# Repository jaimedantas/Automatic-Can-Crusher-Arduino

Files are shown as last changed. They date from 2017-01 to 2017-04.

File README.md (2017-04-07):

# Automatic Can Crusher
This project is a fully automatic can crusher based on the microcontroller ATmega328p Arduino Uno. The machine is made of two hydraulic rams and an Arduino which has a LDR and a LED as a can sensor.
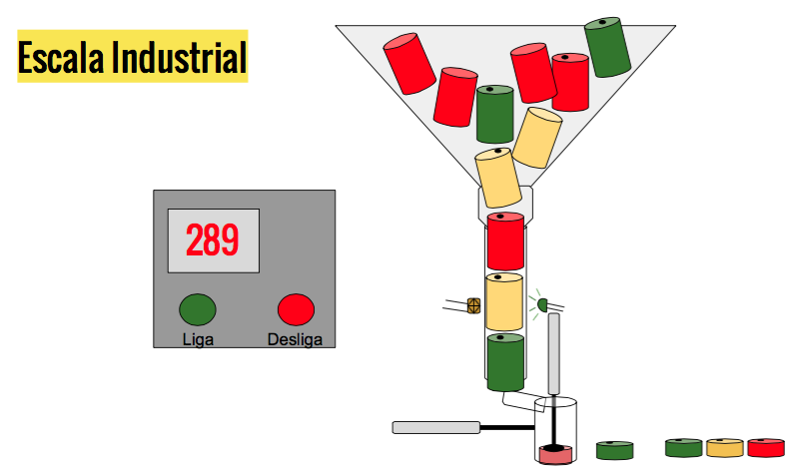
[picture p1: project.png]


There are two relays for switching the hydraulic cylinders. 
### The figure below shows the Arduino and the circuit used

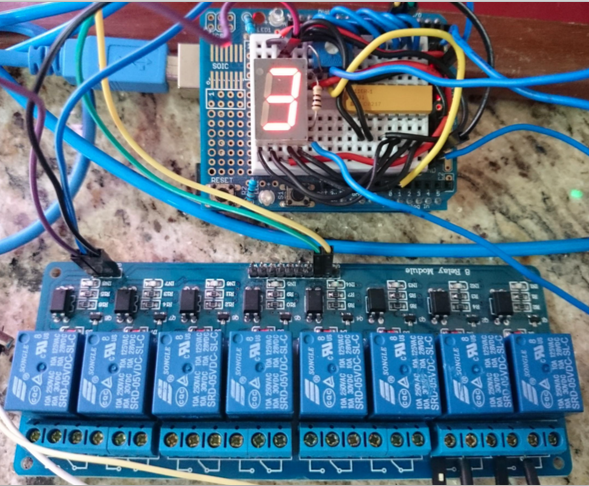
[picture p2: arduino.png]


If you wish to know more about this project, you can read the [report](https://github.com/jaimedantas/Automatic-Can-Crusher-Arduino/blob/master/full_report.pdf) written in Portuguese. You can also watch the video of this project on [YouTube](https://www.youtube.com/watch?v=sCqibvRW4SI)

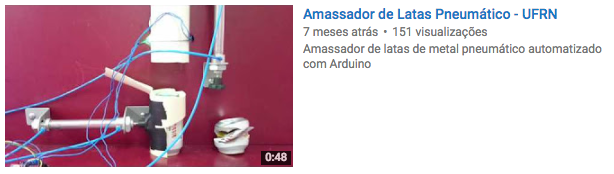
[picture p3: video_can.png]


https://www.youtube.com/watch?v=sCqibvRW4SI

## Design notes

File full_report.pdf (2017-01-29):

# Controle de Sistema Eletropneumático com µC ATmega328P

Alexandre Luz
Ana Jamile
Jaime Dantas
Ramon Fava

# Objetivo

- Desenvolver um amassador de latas utilizando um microcontrolador ATmega 328p e fazendo uso dos conceitos abordados na disciplina de Sistemas Digitais, tais como: interfaces de entrada e saída de dados digitais e analógicos, operações com registradores, conversor analógico e temporizadores.

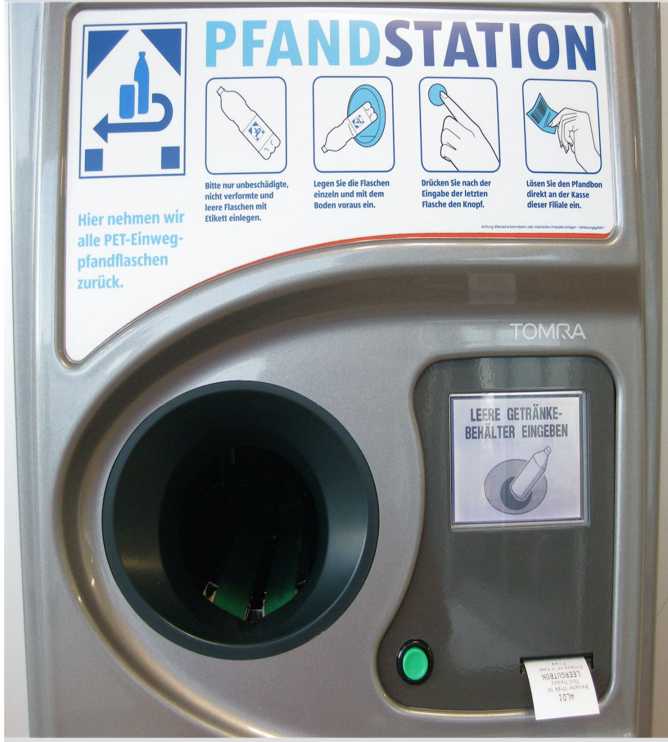
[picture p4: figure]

# Aplicabilidade

- Postos de coleta e compressão de latas em locais de fácil acesso como supermercados.
- Latas por dinheiro.
- Campanhas de incentivo à reciclagem.

# Materiais utilizados

- Cano PVC 75 mm
- Placa de MDF
- Fita isolante
- Arame
- 10 parafusos
- Latas
- 2 atuadores pneumáticos Festo
- Compressor
- Arduino Uno
- 1 LED
- Sensor LDR
- 2 Relés
- 1 Display de 7 segmentos
- Resistências
- Potenciômetro

# Atuadores Pneumáticos - Características

As principais características dos atuadores pneumáticos são:

- Apresentam baixa rigidez devido à compressibilidade do ar
- Não há precisão na parada em posições intermediárias
- Apresentam uma favorável relação peso/potência
- Dimensões reduzidas
- Segurança à sobrecarga
- Facilidade de inversão
- Proteção à explosão

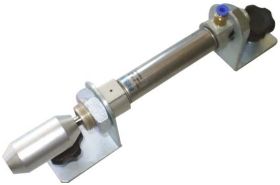
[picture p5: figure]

# Atuadores Pneumáticos - Aplicações

- Prensas pneumáticas
- Dispositivos de fixação de peças em máquinas ferramenta e esteiras
- Acionamento de portas de um ônibus urbano ou dos trens do metrô
- Sistemas automatizados para alimentação de peças
- Robôs industriais para aplicações que não exijam posicionamento preciso

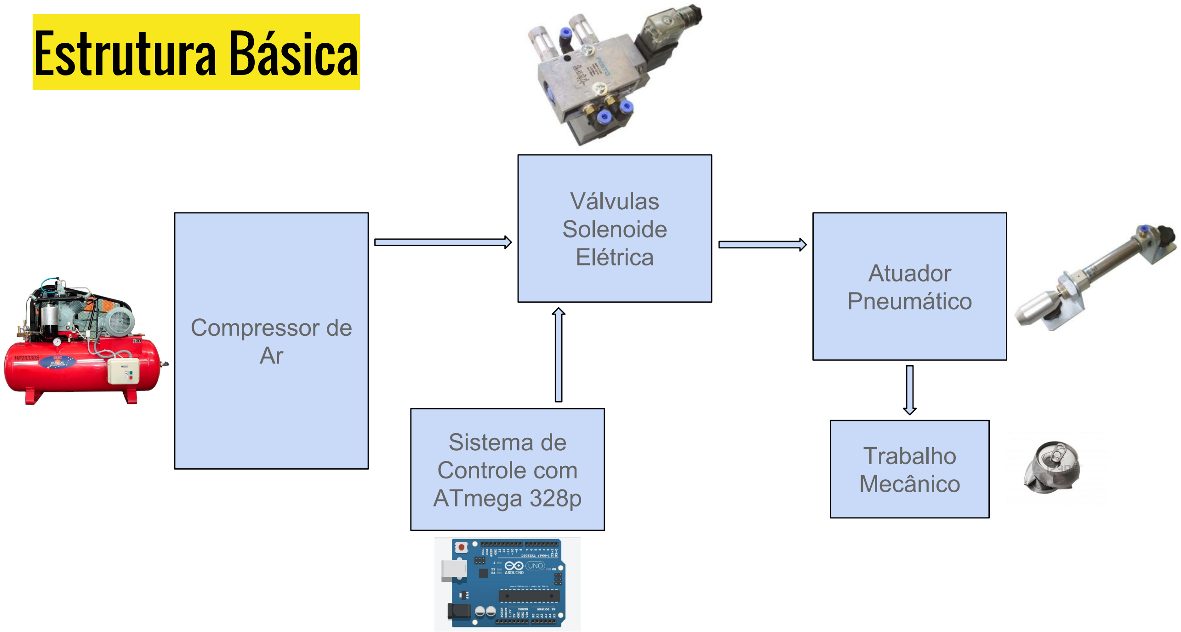
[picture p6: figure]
Estrutura Básica; Sistema de Controle com ATmega 328p; Compressor de Ar; Válvulas Solenoide; Elétrica; Atuador; Pneumático; Trabalho Mecânico

# Válvula Pneumática

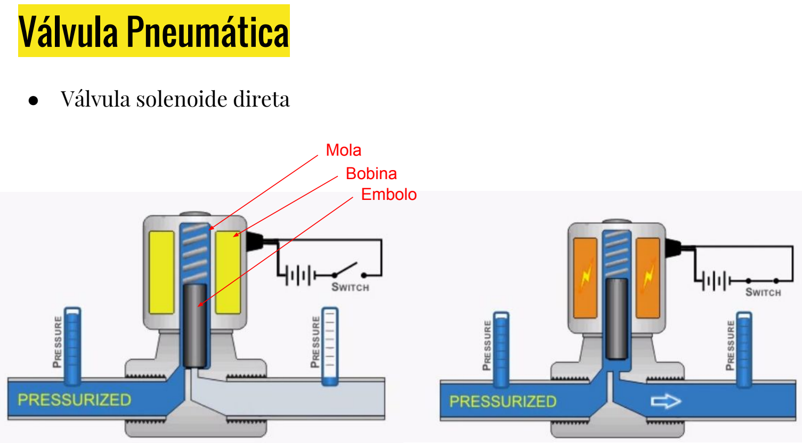
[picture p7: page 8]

- Válvula solenoide direta

Mola
Bobina
| Embolo

# Válvula Pneumática

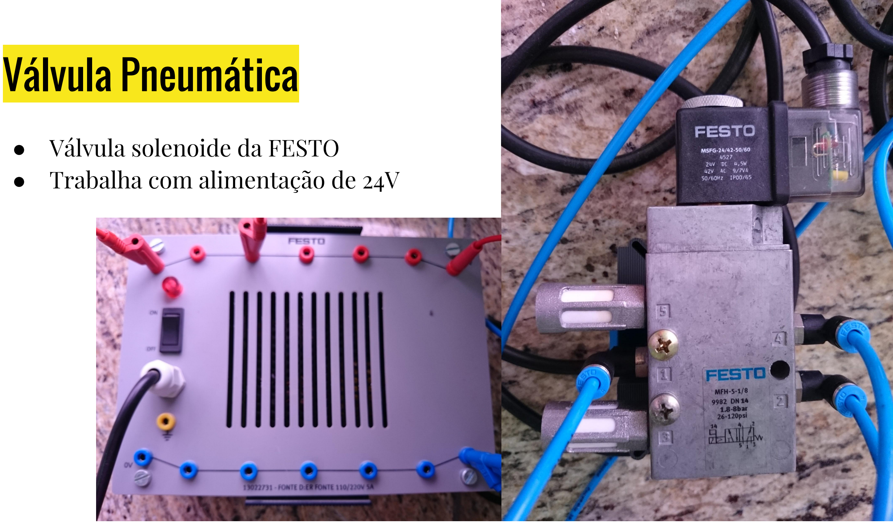
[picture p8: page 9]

- Válvula solenoide da FESTO
- Trabalha com alimentação de 24V

Incidência de Luz | LDR

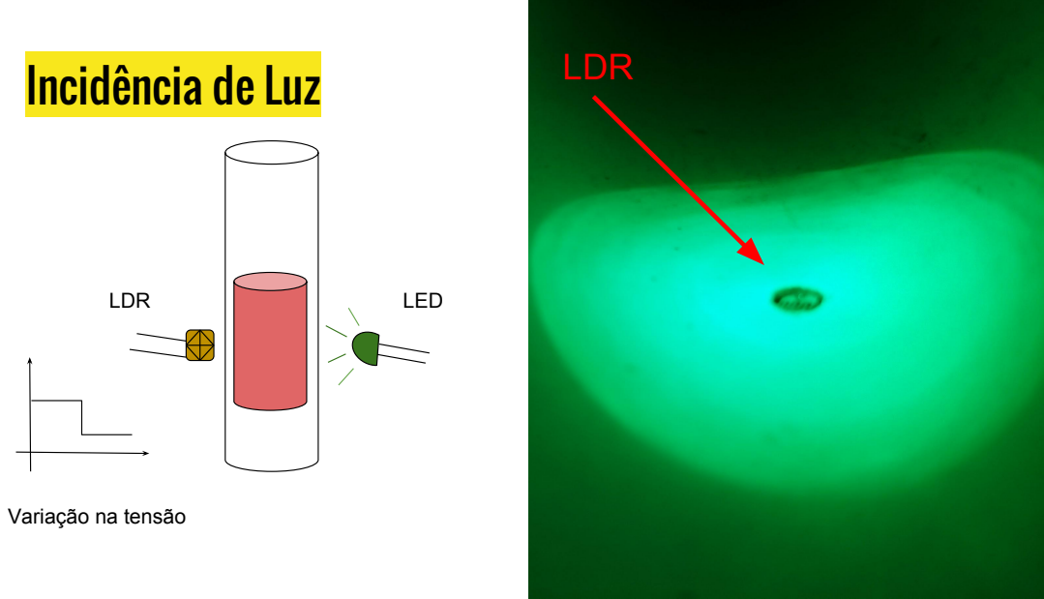
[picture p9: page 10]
LDR; LED

Variação na tensão

# Circuito

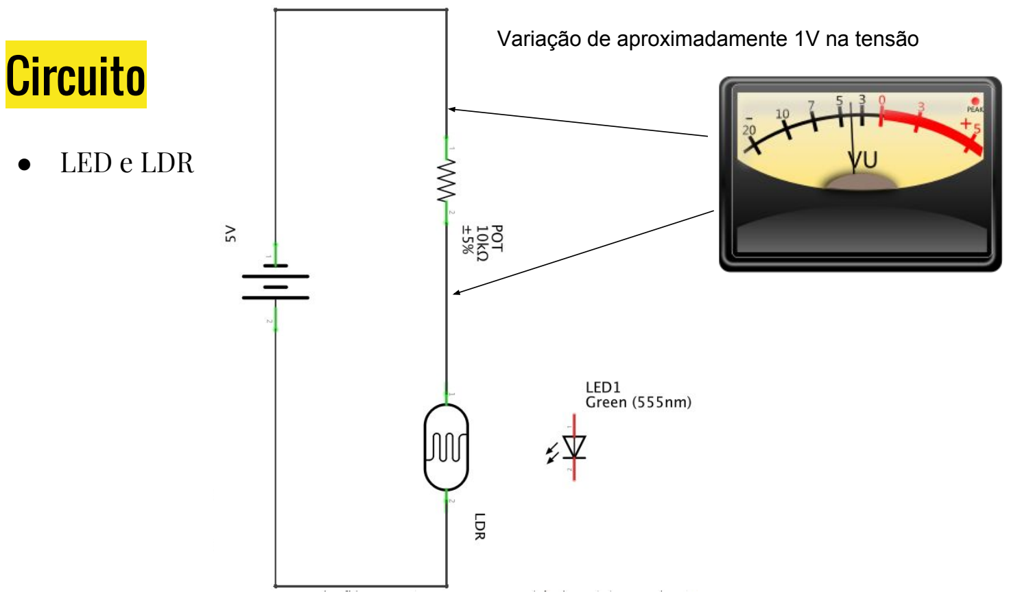
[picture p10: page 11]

- LED e LDR

Variação de aproximadamente 1V na tensão

# Funcionamento

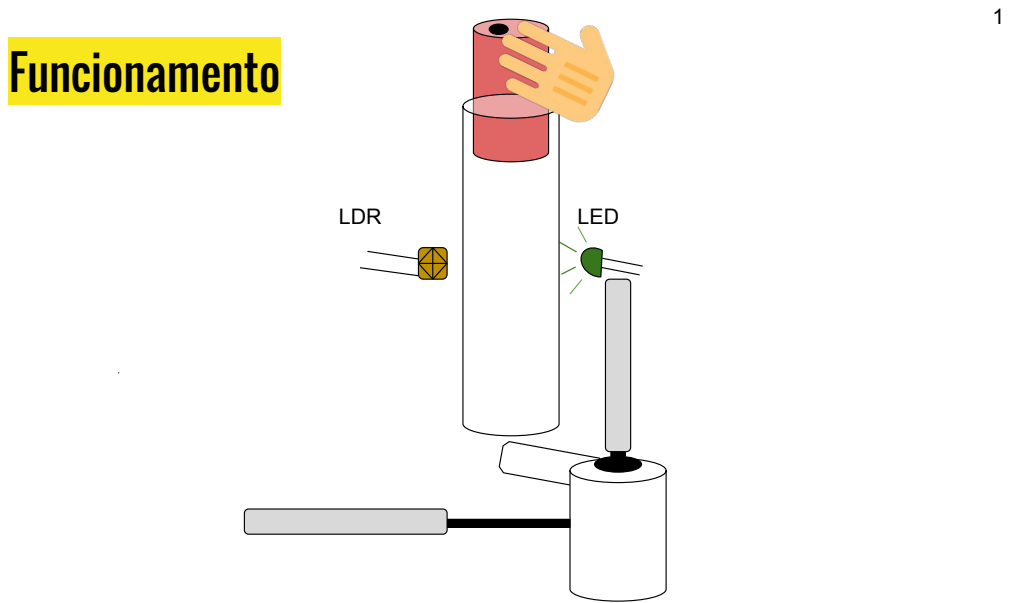
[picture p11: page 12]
LDR; LED

# Funcionamento

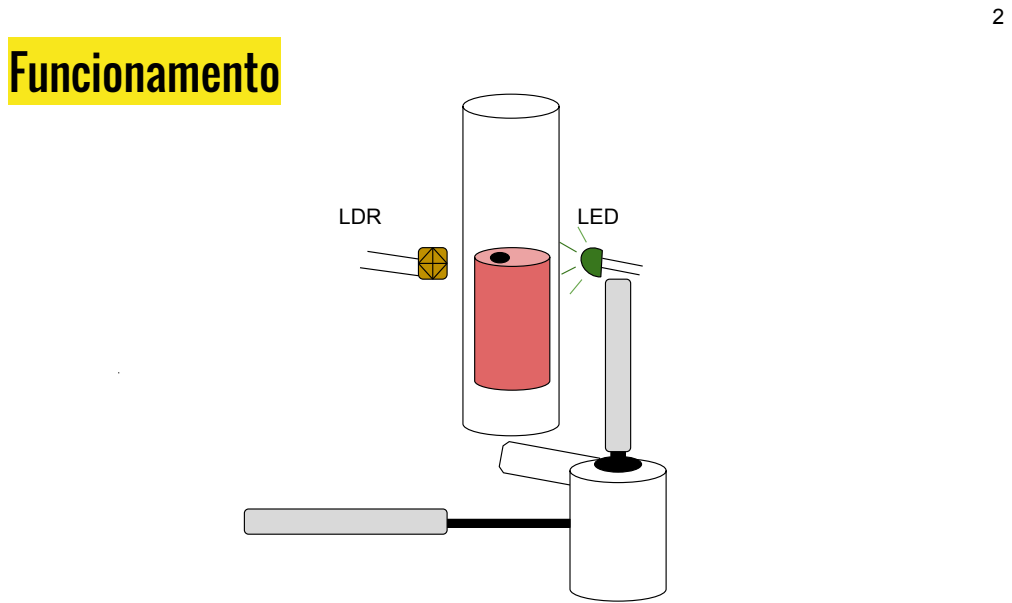
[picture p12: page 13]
LDR; LED

# Funcionamento

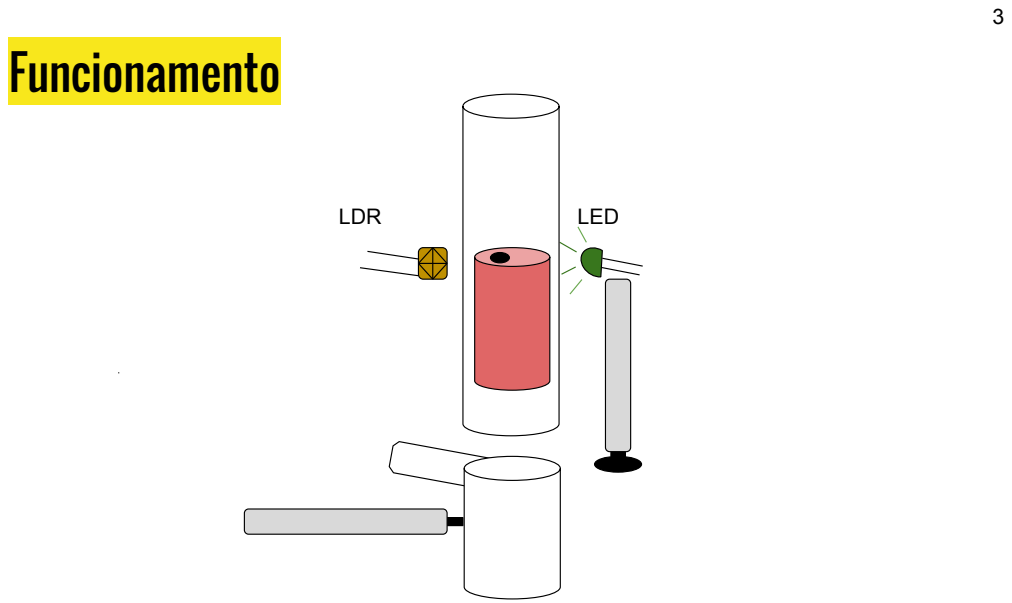
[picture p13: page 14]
LDR; LED

# Funcionamento

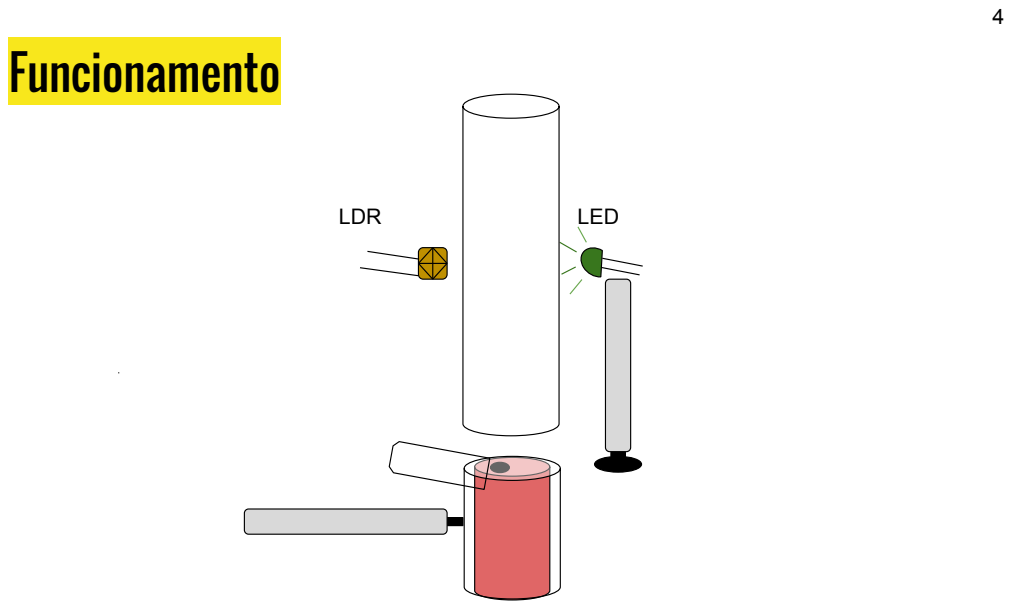
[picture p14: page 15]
LDR; LED

# Funcionamento

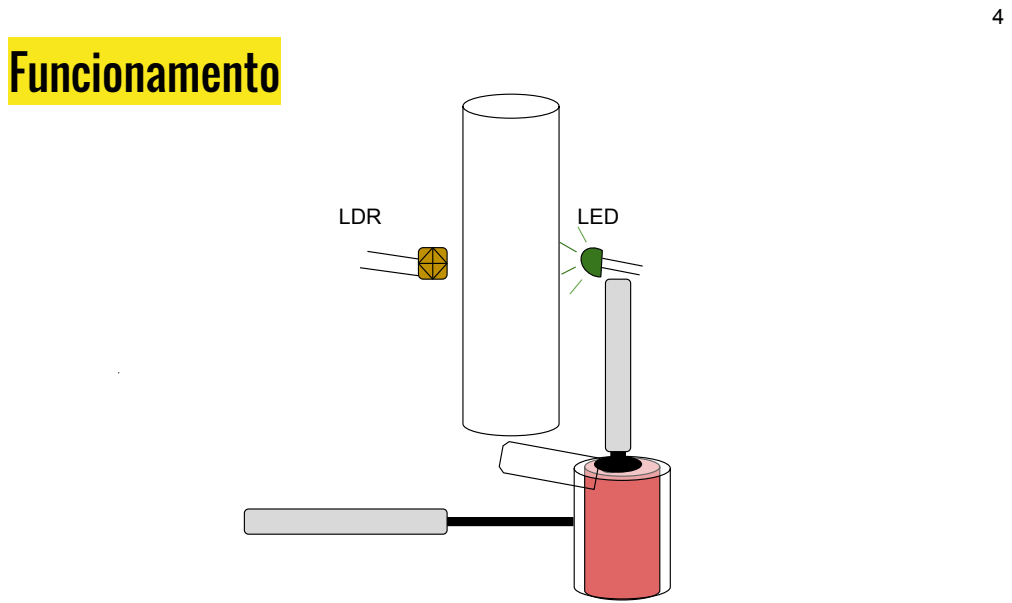
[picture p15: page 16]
LDR; LED

# Funcionamento

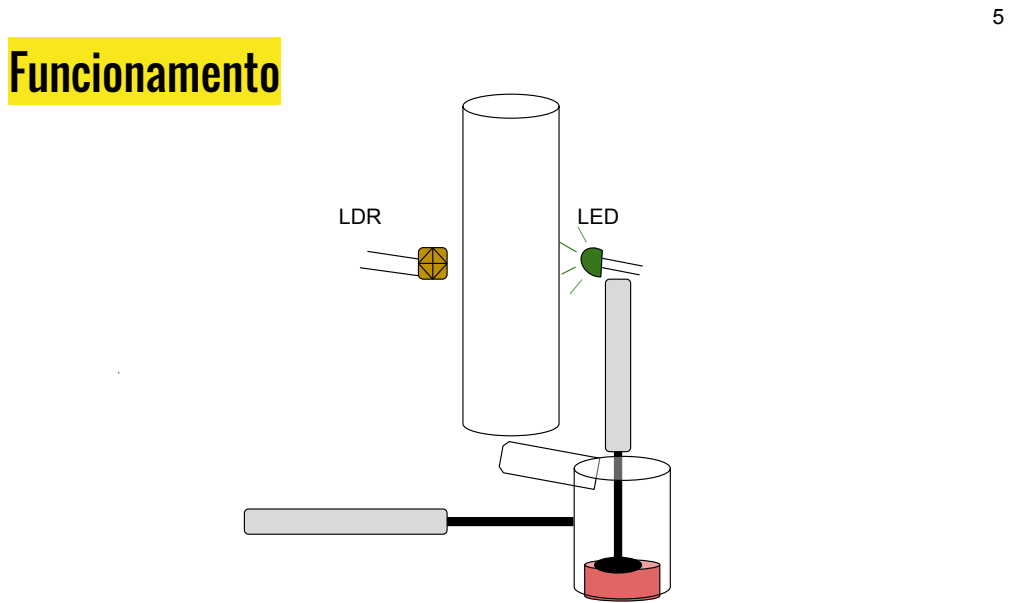
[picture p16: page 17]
LDR; LED

# Escala Industrial

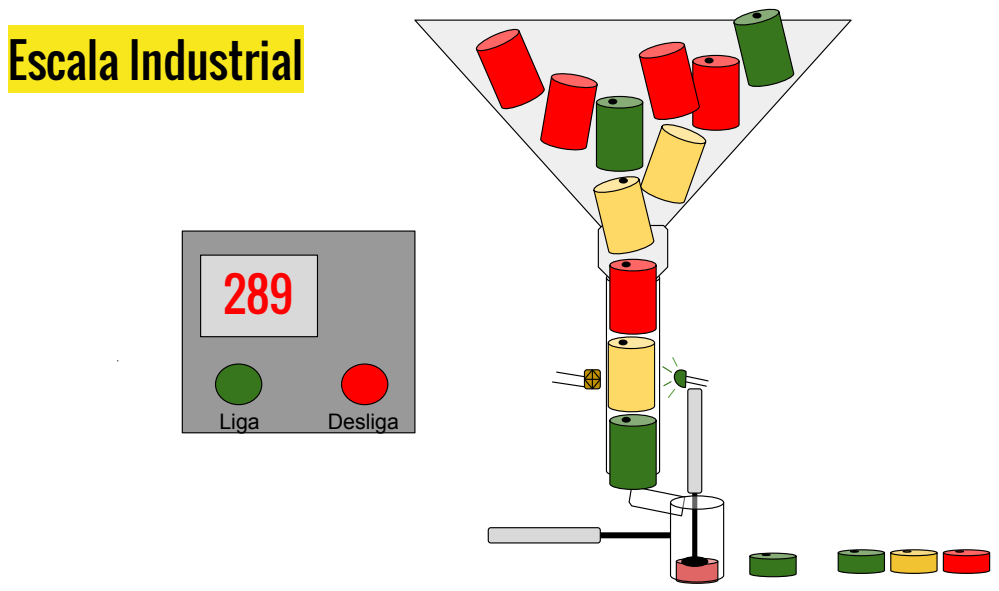
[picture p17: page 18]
Liga; Desliga

# Circuito

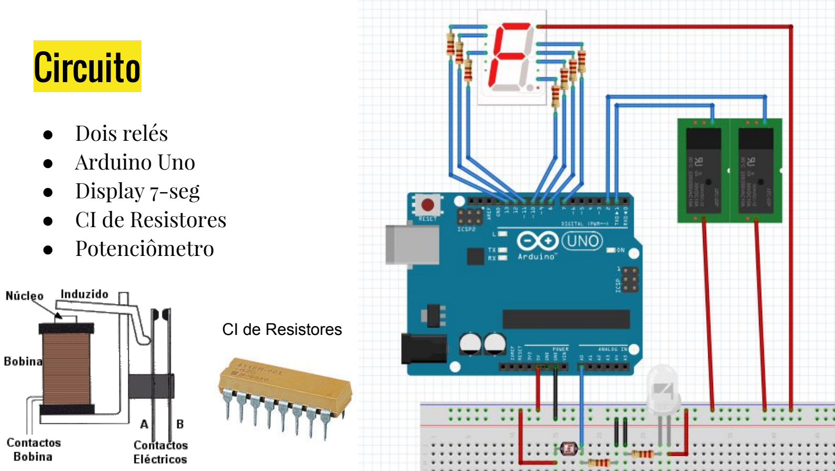
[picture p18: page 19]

CI de Resistores

- Dois relés
- Arduino Uno
- Display 7-seg
- CI de Resistores
- Potenciômetro

# Circuito

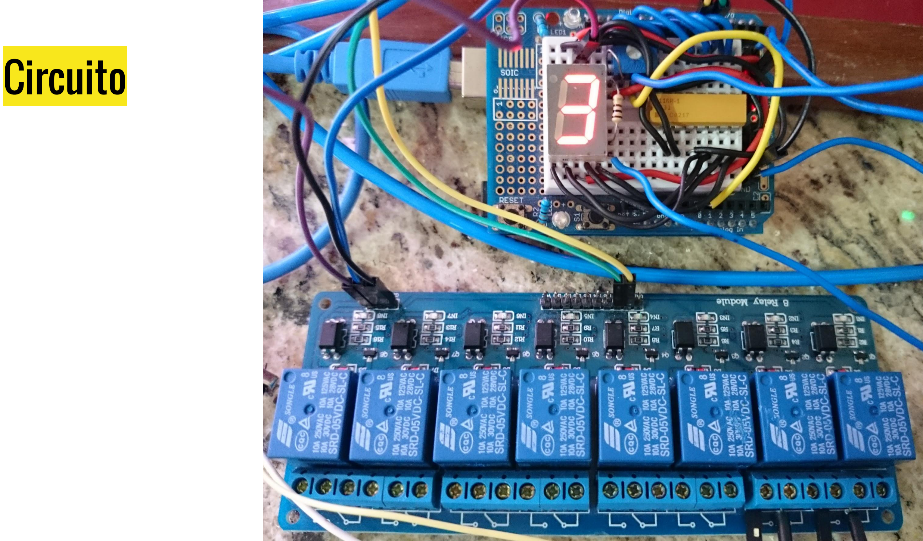
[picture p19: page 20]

# Máquina montada

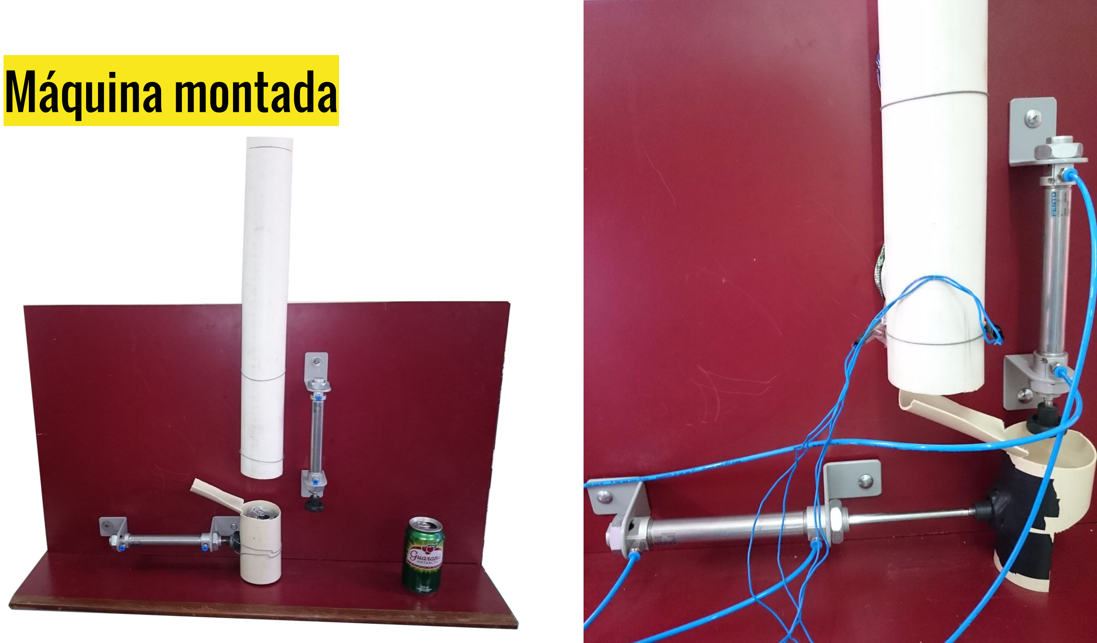
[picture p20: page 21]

# Programação

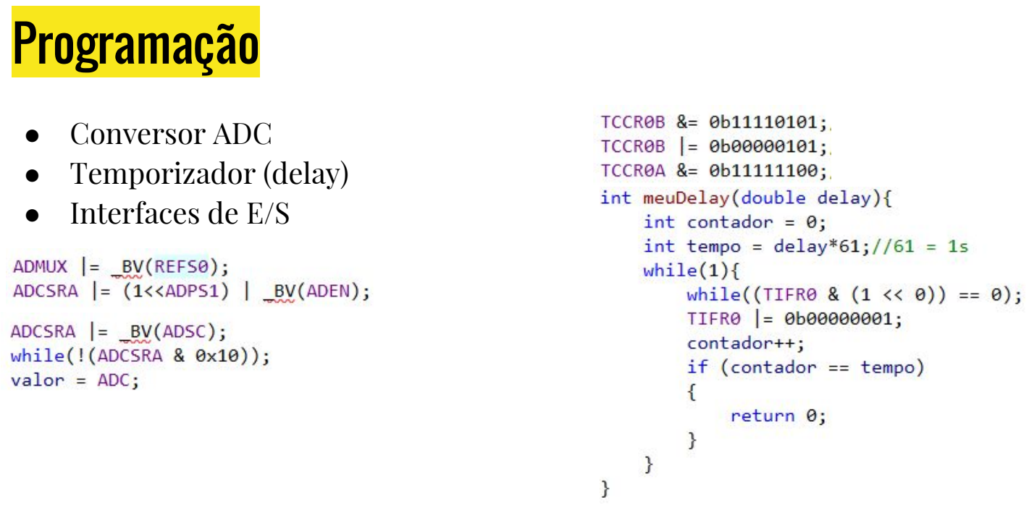
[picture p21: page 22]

- Conversor ADC
- Temporizador (delay)
- Interfaces de E/S

# Vídeo

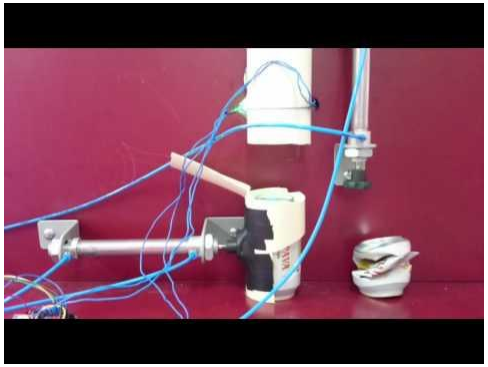
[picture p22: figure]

https://www.youtube.com/watch?v=sCqibvRW4SI

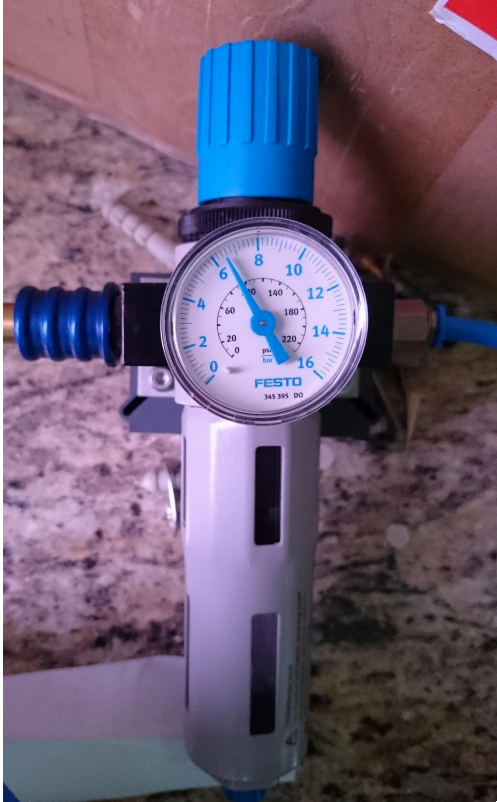
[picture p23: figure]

# Considerações Finais

- Latas previamente cortadas a fim de diminuir suas resistências e, dessa forma, amassá-las.
Isso | acontece | por | consequência | do
compressor utilizado apresentar apenas 6 bar de pressão máxima, não sendo suficiente para vencer a resistência da lata.
- Pressão nominal do atuador de 10 bar

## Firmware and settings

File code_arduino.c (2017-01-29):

#define F_CPU 16000000UL
#include <avr/io.h>

void amassarLata();
int meuDelay(double delay);
void mostrarNum(int num);

int main(void)
{
	ADMUX |= _BV(REFS0);//selecionar entrada do analogico
	ADCSRA |= (1<<ADPS1) | _BV(ADEN);
	
	TCCR0B &= 0b11110101;//setando WGM02 e CS01 como 0
	TCCR0B |= 0b00000101;//setando CS02 e CS00 como 1
	TCCR0A &= 0b11111100;//setando WGM01 e WGM00 como 0;
	
	/*
		Pinos B: 5 - 0, leds do 7 segmentos
		Pino D: 7, led 7 segmentos
		Pinos D: 6 e 5, reles dos pistoes
	*/
	DDRB |= 0b00111111;
	DDRD |= 0b11100000;

	PORTB |= 0b00111111;//leds e reles ativam com sinal baixo
	PORTD |= 0b11100000;
	
	int numLatas = 0;
	float valor;
	mostrarNum(numLatas);
	
	while (1)
	{
		ADCSRA |= _BV(ADSC);
		while(!(ADCSRA & 0x10));
		valor = ADC;
		
		if(valor < 330 ){
			++numLatas;
			if(numLatas > 9)
				numLatas = 0;
				
			mostrarNum(numLatas);
			amassarLata();
		}
	}
}

int meuDelay(double delay){
	int contador = 0;
	int tempo = delay*61;//61 = 1s
	while(1){
		while((TIFR0 & (1 << 0)) == 0);
		TIFR0 |= 0b00000001;
		contador++;
		if (contador == tempo)
		{
			return 0;
		}
	}
}

void amassarLata(){
	PORTD &= 0b10111111;//pegar a lata
	meuDelay(0.5);
	PORTD |= 0b01000000;//volta para amassar
	meuDelay(0.5);
	PORTD &= 0b11011111;//amassa
	meuDelay(0.5);
	PORTD |= 0b00100000;//volta pistao de amassar
	meuDelay(0.5);
}

void mostrarNum(int num){
	PORTB |= 0b00111111;
	PORTD |= 0b10000000;
	switch(num){
		case 1:
			PORTB &= 0b11110110;
			break;
		case 2:
			PORTB &= 0b11100001;
			PORTD &= 0b01111111;
			break;
		case 3:
			PORTB &= 0b11100100;
			PORTD &= 0b01111111;
			break;
		case 4:
			PORTB &= 0b11010110;
			PORTD &= 0b01111111;
			break;
		case 5:
			PORTB &= 0b11001100;
			PORTD &= 0b01111111;
			break;
		case 6:
			PORTB &= 0b11001000;
			PORTD &= 0b01111111;
			break;
		case 7:
			PORTB &= 0b11100110;
			break;
		case 8:
			PORTB &= 0b11000000;
			PORTD &= 0b01111111;
			break;
		case 9:
			PORTB &= 0b11000100;
			PORTD &= 0b01111111;
			break;
		case 0:
			PORTB &= 0b11000000;
			break;
		default:
			break;
	}
}
